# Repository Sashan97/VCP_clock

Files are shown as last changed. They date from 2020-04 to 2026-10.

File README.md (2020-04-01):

# VCP clock
Replica of Vilnius Central Post electronic clock

### CLOCK:
* 3D printed case
* Uses Arduino Nano, DS3231 RTC module and WS2812 LED strips
* Supports Bluetooth connection via HC06

### APP:
* Designed in Thunkable
* Allows to turn the clock on and off, adjust time and brightness and toggle lantern mode

### SERIAL PORT TERMINAL COMMUNICATION:

Some advanced clock settings can be changed through the serial port terminal via Bluetooth.

Command syntax:

set,arg1,arg2,arg3,arg4,arg5,arg6,arg7

* arg1 - power, 0 is off, 1 is on.
* arg2 - brightness, 0-255.
* arg3 - lantern mode, 0 is off, 1 is on.
* arg4 - color, 1 - original, 2 - red, 3 - green, 4 - blue.
* arg5 - auto mode, turns clock off and on at certain hours, 0 is off, 1 is on.
* arg6 - auto mode start hour, ignored if arg5 is 0.
* arg7 - auto mode stop our, ignored if arg5 is 0.

For example, sending **set,1,50,0,1,1,7,23** will turn the clock with the brightness 50, without the lantern mode, using original color. Automatic mode will shut down the clock at 23 and turn it on at 7 next day. Notice, that if the command will be sent between 23 and 7, time will not be shown.

Also you can override date and time via terminal by sending

time,arg1,arg2,arg3,arg4,arg5,arg6,arg7

* arg1 - hours 0-23
* arg2 - minutes
* arg3 - seconds
* arg4 - month 1-12
* arg5 - day
* arg6 - year (2 last digits)
* arg7 - day of week 1-7

For example, sending **time,14,21,0,3,4,20,2** will set the time and date to 14:21:00, 3rd of April, 2020, Tuesday.

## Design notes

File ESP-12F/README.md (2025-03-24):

### Idea
**Swap Arduino Nano to ESP-12F to enable time syncronization with time server.**

### Pros
- RTC clock module is redundant and can be removed - ESP-12F has RTC memery.
- Bluetooth module is redundant and can be removed - web page will be used to adjust settings.

### Cons
- ESP-12F is 3.3V, so the voltage regulator is necessary.
- Also logic level converter will be necessary to work with WS2812B RGB strips.

### Possible solutions
- Voltage regulator - AMS1117 or MP2315
- Logic level converter - 74HCT125
- WiFiManager.h library to manage Wi-Fi credentials

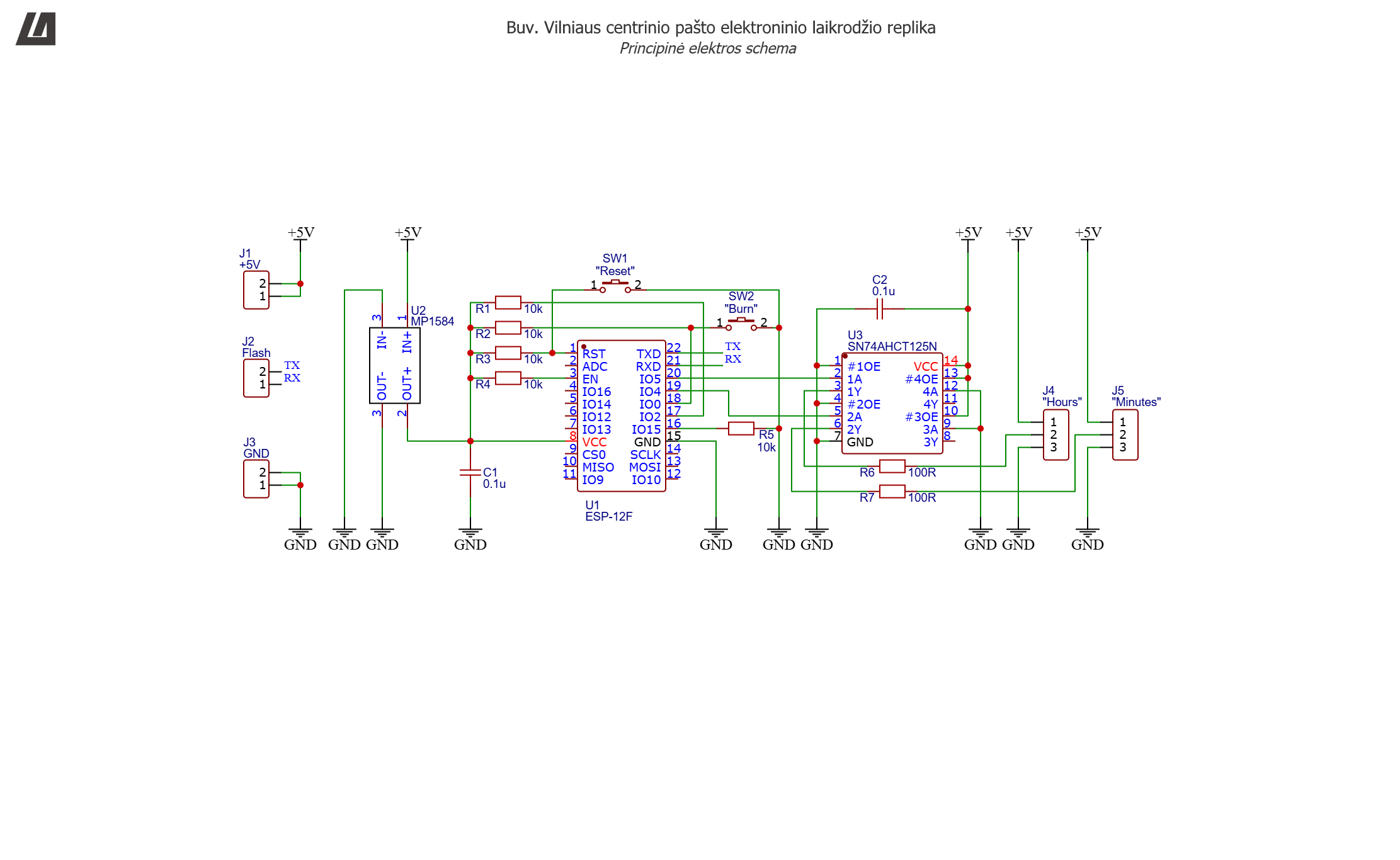
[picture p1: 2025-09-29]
ESP-12F/Hardware/circuit_diagram.png

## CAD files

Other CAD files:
3D/Clock_main v1.f3d

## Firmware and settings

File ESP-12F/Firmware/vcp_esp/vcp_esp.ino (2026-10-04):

#include <WiFiManager.h>
#include <ESP8266Wifi.h>
#include <ESP8266WebServer.h>
#include <WiFiUdp.h>
#include <Ticker.h>
#include <NTPClient.h>
#include <Adafruit_NeoPixel.h>
#include <EEPROM.h>

#define HOUR_LED_AMOUNT 36
#define MINUTE_LED_AMOUNT 72
#define HOURS_PIN 5
#define MINUTES_PIN 4

#define DEFAULT_OFFSET 2
#define DEFAULT_ON_HOUR 7
#define DEFAULT_ON_MINUTE 0
#define DEFAULT_OFF_HOUR 23
#define DEFAULT_OFF_MINUTE 0
#define DEFAULT_MAX_CONNECTION_ATTEMPTS 3
#define DEFAULT_WAIT_PER_ATTEMPT 30

ESP8266WebServer server(80);

WiFiUDP ntpUDP;
NTPClient timeClient(ntpUDP, "pool.ntp.org", 0, 3600000);

Ticker displayTicker;

WiFiManager wifiManager;

Adafruit_NeoPixel hourStrip = Adafruit_NeoPixel(HOUR_LED_AMOUNT, HOURS_PIN, NEO_GRB + NEO_KHZ800);
Adafruit_NeoPixel minuteStrip = Adafruit_NeoPixel(MINUTE_LED_AMOUNT, MINUTES_PIN, NEO_GRB + NEO_KHZ800);

int brightness = 50;
uint32_t color = 0;

bool clockActive = true;

struct ClockSettings {
  uint32_t magic;

  long utcOffsetInSeconds;
  bool autoOnOffEnabled;
  bool dstEnabled;
  int offHour;
  int offMinute;
  int onHour;
  int onMinute;
  int maxConnectionAttempts;
  int waitPerAttempt;
};

const uint32_t SETTINGS_MAGIC = 0x434C4B31; // "CLK1"

ClockSettings settings;

volatile bool displayUpdateRequested = false;

bool clockServerStarted = false;

bool portalAnimationPixels[MINUTE_LED_AMOUNT] = { false };
uint8_t portalAnimationPixelCount = 0;

unsigned long lastPortalAnimationUpdate = 0;

const unsigned long PORTAL_ANIMATION_INTERVAL = 3000UL;
const uint8_t PORTAL_ANIMATION_MAX_PIXELS = 10;

void requestDisplayUpdate() {
  displayUpdateRequested = true;
}

bool isInOnOffInterval(int curMin, int offMin, int onMin) {
  if (offMin == onMin) return false;
  if (offMin < onMin) {
    return (curMin >= offMin && curMin < onMin);
  } else {
    // for cases involving the transition through midnight
    return (curMin >= offMin) || (curMin < onMin);
  }
}

void saveSettings() {
  EEPROM.put(0, settings);
  EEPROM.commit();
}

void loadSettings() {
  EEPROM.get(0, settings);

  if (settings.magic != SETTINGS_MAGIC) {
    settings.utcOffsetInSeconds = DEFAULT_OFFSET * 3600;
    settings.autoOnOffEnabled = false;
    settings.dstEnabled = true;
    settings.offHour = DEFAULT_OFF_HOUR;
    settings.offMinute = DEFAULT_OFF_MINUTE;
    settings.onHour = DEFAULT_ON_HOUR;
    settings.onMinute = DEFAULT_ON_MINUTE;
    settings.maxConnectionAttempts = DEFAULT_MAX_CONNECTION_ATTEMPTS;
    settings.waitPerAttempt = DEFAULT_WAIT_PER_ATTEMPT;
    saveSettings();
  }
}

bool isDST(int year, int month, int day, int hourUTC) {
  int lastSundayMarch = 31 - ((5 * year / 4 + 4) % 7);
  int lastSundayOctober = 31 - ((5 * year / 4 + 1) % 7);

  if (month > 3 && month < 10) {
    return true;
  }

  if (month == 3) {
    if (day > lastSundayMarch) return true;
    if (day < lastSundayMarch) return false;

    return hourUTC >= 1;
  }

  if (month == 10) {
    if (day < lastSundayOctober) return true;
    if (day > lastSundayOctober) return false;

    return hourUTC < 1;
  }

  return false;
}

void updateTimeOffset() {
  timeClient.setTimeOffset(0);

  time_t utcTime = timeClient.getEpochTime();
  struct tm *utcInfo = gmtime(&utcTime);

  bool dst = false;

  if (settings.dstEnabled) {
    dst = isDST(
      utcInfo->tm_year + 1900,
      utcInfo->tm_mon + 1,
      utcInfo->tm_mday,
      utcInfo->tm_hour
    );
  }

  long effectiveOffset = settings.utcOffsetInSeconds;

  if (dst) {
    effectiveOffset += 3600L;
  }

  timeClient.setTimeOffset(effectiveOffset);
}

void setHourPixels(int hours) {
  hourStrip.clear();
  int hourLedIndex = hours * 3;

  if (hours >= 12)
    hourLedIndex -= 36;

  for (int i = hourLedIndex; i < (hourLedIndex + 3); i++) {
    hourStrip.setPixelColor(i, color);
  }
}

void setMinutePixels(int minutes) {
  if (minutes == 0) {
    minuteStrip.clear();
  }

  int minutesUntilTile = 5;
  int tileAmount = minutes + minutes / 5;

  for (int i = 0; i < tileAmount; i++) {
    if (minutesUntilTile > 0) {
      minuteStrip.setPixelColor(i, color);
      minutesUntilTile--;
    } else {
      minuteStrip.setPixelColor(i, 0x000000);
      minutesUntilTile = 5;
    }
  }
}

void displayTime() {
  Serial.println(timeClient.getFormattedTime());

  int hours = timeClient.getHours();
  int minutes = timeClient.getMinutes();

  int minutesSinceMidnight = hours * 60 + minutes;
  int offMin = settings.offHour * 60 + settings.offMinute;
  int onMin = settings.onHour * 60 + settings.onMinute;

  bool shouldBeActive = true;
  if (settings.autoOnOffEnabled) {
    if (isInOnOffInterval(minutesSinceMidnight, offMin, onMin)) {
      shouldBeActive = false;
    } else {
      shouldBeActive = true;
    }
  }

  if (shouldBeActive != clockActive) {
    clockActive = shouldBeActive;
    if (!clockActive) {
      hourStrip.clear();
      minuteStrip.clear();
      hourStrip.show();
      minuteStrip.show();
    } else {
      setHourPixels(hours);
      hourStrip.show();
      setMinutePixels(minutes);
      minuteStrip.show();
    }
  }

  if (!clockActive) return;

  // Display hours
  setHourPixels(hours);
  hourStrip.show();

  // Display minutes
  setMinutePixels(minutes);
  minuteStrip.show();
}

bool isMinuteSeparatorPixel(int pixel) {
  // Minute strip is arranged as:
  // 5 minute LEDs, 1 separator, repeated.
  return (pixel % 6) == 5;
}


void resetConfigPortalAnimation() {
  for (int i = 0; i < MINUTE_LED_AMOUNT; i++) {
    portalAnimationPixels[i] = false;
  }

  portalAnimationPixelCount = 0;

  // Make the first pixel appear immediately.
  lastPortalAnimationUpdate = millis() - PORTAL_ANIMATION_INTERVAL;

  // Remove the old clock display when entering ConfigPortal.
  hourStrip.clear();
  minuteStrip.clear();

  hourStrip.show();
  minuteStrip.show();
}

void updateConfigPortalAnimation() {
  unsigned long now = millis();

  if (now - lastPortalAnimationUpdate < PORTAL_ANIMATION_INTERVAL) {
    return;
  }

  lastPortalAnimationUpdate = now;

  // Pick a new, currently inactive, non-separator pixel.
  int newPixel;

  do {
    newPixel = random(MINUTE_LED_AMOUNT);
  }
  while (
    isMinuteSeparatorPixel(newPixel) ||
    portalAnimationPixels[newPixel]
  );

  portalAnimationPixels[newPixel] = true;
  portalAnimationPixelCount++;

  if (portalAnimationPixelCount > PORTAL_ANIMATION_MAX_PIXELS) {
    int pixelToRemove;

    do {
      pixelToRemove = random(MINUTE_LED_AMOUNT);
    }
    while (
      isMinuteSeparatorPixel(pixelToRemove) ||
      !portalAnimationPixels[pixelToRemove] ||
      pixelToRemove == newPixel
    );

    portalAnimationPixels[pixelToRemove] = false;
    portalAnimationPixelCount--;
  }

  // Render complete animation state.
  minuteStrip.clear();

  for (int i = 0; i < MINUTE_LED_AMOUNT; i++) {
    if (portalAnimationPixels[i]) {
      minuteStrip.setPixelColor(i, color);
    }
  }

  minuteStrip.show();
}

void handleRoot() {
  int tzHours = settings.utcOffsetInSeconds / 3600;

  uint32_t c = color;
  uint8_t r = (c >> 16) & 0xFF;
  uint8_t g = (c >> 8) & 0xFF;
  uint8_t b = c & 0xFF;
  char colorHex[8];
  sprintf(colorHex, "#%02X%02X%02X", r, g, b);

  char offBuf[6], onBuf[6];
  sprintf(offBuf, "%02d:%02d", settings.offHour, settings.offMinute);
  sprintf(onBuf, "%02d:%02d", settings.onHour, settings.onMinute);

  String autoOnOffChecked = settings.autoOnOffEnabled ? "checked" : "";
  String dstChecked = settings.dstEnabled ? "checked" : "";

  String page = String(R"rawliteral(
  <!DOCTYPE html>
  <html>
  <head>
    <meta charset="UTF-8">
    <title>Clock Settings</title>
    <style>
      body { font-family: Arial, sans-serif; margin: 20px; background: #f5f5f5; }
      h1 { color: #222; }
      form { background: #fff; padding: 20px; border-radius: 8px; box-shadow: 0 0 5px rgba(0,0,0,0.2); max-width: 420px; }
      label { display: block; margin-top: 12px; }
      input[type=number], input[type=color], input[type=time] {
        padding: 6px; width: 100%; box-sizing: border-box; margin-top: 6px;
      }
      input[type=submit] {
        margin-top: 18px; padding: 10px 18px;
        background: #4CAF50; color: white; border: none;
        border-radius: 4px; cursor: pointer;
      }
      input[type=submit]:hover { background: #45a049; }
    </style>
  </head>
  <body>
    <h1>Clock Settings</h1>
    <form action="/save" method="POST">
  )rawliteral");

  page += String("<label>Timezone offset (hours):<input type=\"number\" name=\"tz\" value=\"") + String(tzHours) + String("\" step=\"1\" min=\"-12\" max=\"12\"></label>\n");

  page += "<label><input type=\"checkbox\" name=\"auto_dst\" " + dstChecked + "> Perform DST trasition</label>\n";

  page += String("<label>Brightness (0-255):<input type=\"number\" name=\"brightness\" value=\"") + String(brightness) + String("\" min=\"0\" max=\"255\"></label>\n");

  page += String("<label>LED color:<input type=\"color\" name=\"color\" value=\"") + String(colorHex) + String("\"></label>\n");

  page += "<label><input type=\"checkbox\" name=\"auto_onoff\" " + autoOnOffChecked + "> Enable automatic on/off</label>\n";

  page += String("<label>Auto-off start time:<input type=\"time\" name=\"off_time\" value=\"") + String(offBuf) + String("\"></label>\n");

  page += String("<label>Auto-on start time:<input type=\"time\" name=\"on_time\" value=\"") + String(onBuf) + String("\"></label>\n");

  page += String("<label>Wi-Fi connection attempts (0-10):<input type=\"number\" name=\"max_attempts\" value=\"") + String(settings.maxConnectionAttempts) + String("\" min=\"0\" max=\"10\"></label>\n");

  page += String("<label>Wait per attempt, s (0-100):<input type=\"number\" name=\"wait_per_attempt\" value=\"") + String(settings.waitPerAttempt) + String("\" min=\"0\" max=\"100\"></label>\n");
  
  page += R"rawliteral(
      <input type="submit" value="Save settings">
    </form>
  </body>
  </html>
  )rawliteral";

  page += R"rawliteral(
  <hr>
  <form action="/forget" method="POST">
    <input type="submit" value="Forget Wi-Fi and reboot">
  </form>
  )rawliteral";

  server.send(200, "text/html", page);
}

void handleSave() {
  if (server.hasArg("tz")) {
    int tz = server.arg("tz").toInt();
    settings.utcOffsetInSeconds = tz * 3600;
  }

  if (server.hasArg("auto_dst")) {
    settings.dstEnabled = true;
  } else {
    settings.dstEnabled = false;
  }

  if (server.hasArg("brightness")) {
    int b = server.arg("brightness").toInt();
    if (b < 0) b = 0;
    if (b > 255) b = 255;
    brightness = b;

    hourStrip.setBrightness(brightness);
    minuteStrip.setBrightness(brightness);
  }

  if (server.hasArg("color")) {
    String hex = server.arg("color");  // например, "#fca503"
    long number = strtol(hex.substring(1).c_str(), NULL, 16);

    int r = (number >> 16) & 0xFF;
    int g = (number >> 8) & 0xFF;
    int b = number & 0xFF;

    color = minuteStrip.Color(r, g, b);
  }

  if (server.hasArg("auto_onoff")) {
    settings.autoOnOffEnabled = true;
  } else {
    settings.autoOnOffEnabled = false;
  }

  if (server.hasArg("off_time")) {
    String offTime = server.arg("off_time");
    if (offTime.length() >= 5) {
      settings.offHour = offTime.substring(0, 2).toInt();
      settings.offMinute = offTime.substring(3, 2 + 3).toInt();
    }
  }

  if (server.hasArg("on_time")) {
    String onTime = server.arg("on_time");
    if (onTime.length() >= 5) {
      settings.onHour = onTime.substring(0, 2).toInt();
      settings.onMinute = onTime.substring(3, 2 + 3).toInt();
    }
  }

  if (server.hasArg("max_attempts")) {
    int attempts = server.arg("max_attempts").toInt();
    if (attempts < 0) attempts = 0;
    if (attempts > 10) attempts = 10;
    settings.maxConnectionAttempts = attempts;
  }

  if (server.hasArg("wait_per_attempt")) {
    int delay = server.arg("wait_per_attempt").toInt();
    if (delay < 0) delay = 0;
    if (delay > 100) delay = 100;
    settings.waitPerAttempt = delay;
  }

  saveSettings();

  updateTimeOffset();

  server.send(200, "text/html",
              "<h1>Settings saved!</h1><p><a href='/'>Back to settings</a></p>");
}

void handleNotFound() {
  server.send(404, "text/plain", "Not found");
}

void startClockConfigPortal() {
  Serial.println("Starting ConfigPortal...");

  resetConfigPortalAnimation();

  wifiManager.startConfigPortal("VCP-Clock");
}

void startClockServer() {
  if (clockServerStarted) {
    return;
  }

  server.begin();
  clockServerStarted = true;

  Serial.println("Clock web server started.");
}

void connectWiFiOrPortal() {
  if (!wifiManager.getWiFiIsSaved()) {
  Serial.println("No saved Wi-Fi credentials.");
  startClockConfigPortal();
  return;
}
  
  WiFi.begin();

  bool connected = false;

  int pos = 0;
  int dir = 1;
  unsigned long lastAnim = 0;
  const unsigned long animInterval = 500;

  for (int attempt = 1; attempt <= settings.maxConnectionAttempts; attempt++) {
    unsigned long start = millis();
    while (WiFi.status() != WL_CONNECTED && (millis() - start) < (settings.waitPerAttempt * 1000)) {
      delay(50);

      if (millis() - lastAnim > animInterval) {
        lastAnim = millis();

        minuteStrip.clear();
        if (pos < 5) {
          minuteStrip.setPixelColor(pos, minuteStrip.Color(255, 0, 0));
        }
        minuteStrip.show();

        pos += dir;
        if (pos == 0 || pos == 4) dir = -dir;
      }
    }
    if (WiFi.status() == WL_CONNECTED) {
      connected = true;
      break;
    }
  }

  minuteStrip.clear();
  minuteStrip.show();

  if (!connected) {
    startClockConfigPortal();
  }
}

void handleForgetWiFi() {
  server.send(200, "text/html",
              "<h1>Forgetting Wi-Fi...</h1><p>Device will reboot.</p>");
  
  delay(200);

  wifiManager.resetSettings();

  delay(500);
  ESP.restart();
}

void setup() {
  pinMode(HOURS_PIN, OUTPUT);
  pinMode(MINUTES_PIN, OUTPUT);

  Serial.begin(9600);
  EEPROM.begin(512);
  loadSettings();

  hourStrip.begin();
  minuteStrip.begin();

  hourStrip.setBrightness(brightness);
  minuteStrip.setBrightness(brightness);
  color = minuteStrip.Color(252, 165, 3);

  WiFi.mode(WIFI_STA);
  wifiManager.setConfigPortalBlocking(false);
  wifiManager.setDisableConfigPortal(true);

  randomSeed(micros());

  connectWiFiOrPortal();

  timeClient.begin();
  timeClient.setTimeOffset(0);

  if (timeClient.update()) {
    updateTimeOffset();
  }

  displayTicker.attach(1, requestDisplayUpdate);

  server.on("/", handleRoot);
  server.on("/save", HTTP_POST, handleSave);
  server.on("/forget", HTTP_POST, handleForgetWiFi);
  server.onNotFound(handleNotFound);
  if (!wifiManager.getConfigPortalActive()) {
    startClockServer();
  }
}

void loop() {
  // ------------------------------------------------------------
  // CONFIG PORTAL MODE
  // ------------------------------------------------------------
  if (wifiManager.getConfigPortalActive()) {

    bool connected = wifiManager.process();

    displayUpdateRequested = false;

    if (connected && WiFi.status() == WL_CONNECTED) {
      Serial.println("Wi-Fi configured successfully.");

      startClockServer();

      if (timeClient.forceUpdate()) {
        updateTimeOffset();
      }

      minuteStrip.clear();
      minuteStrip.show();

      displayTime();

      return;
    }

    updateConfigPortalAnimation();

    return;
  }


  // ------------------------------------------------------------
  // NORMAL CLOCK MODE
  // ------------------------------------------------------------
  if (!clockServerStarted && WiFi.status() == WL_CONNECTED) {
    startClockServer();
  }

  if (clockServerStarted) {
    server.handleClient();
  }


  if (displayUpdateRequested) {
    displayUpdateRequested = false;
    displayTime();
  }


  if (timeClient.update()) {
    updateTimeOffset();
  }


  static unsigned long lastDstCheck = 0;

  if (millis() - lastDstCheck >= 60000UL) {
    lastDstCheck = millis();
    updateTimeOffset();
  }
}

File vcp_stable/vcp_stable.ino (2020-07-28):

#include <Adafruit_NeoPixel.h>
#include <iarduino_RTC.h>

int lastMinute;
int lastMode;
bool isOn = true;
bool isActive = true;

//settings
int bpower = 1;       // 0 - off, 1 - on
int bbright = 50;      // brightness 0-250
int bmodes = 1;       // 1 - clock, 2 - illumination, 3 - lamp
int bcolor = 1;       // 1 - original, 2 - red, 3 - green, 4 - blue
int bauto = 0;        // automatic start and stop 0 - off, 1 - on
int bautostart = 0;   //start time, if auto is on
int bautostop = 0;    //stop time, if auto is off

//bluetooth data input
const byte numChars = 32;
char receivedChars[numChars];
char tempChars[numChars];        // temporary array for use when parsing
bool newData = false;

String mode;            // set time (time) or adjust settings (set)

int arg1 = 0;
int arg2 = 0;
int arg3 = 0;
int arg4 = 0;
int arg5 = 0;
int arg6 = 0;
int arg7 = 0;

//LED strips
Adafruit_NeoPixel hourStrip = Adafruit_NeoPixel(36, 13, NEO_GRB + NEO_KHZ800);
Adafruit_NeoPixel minuteStrip = Adafruit_NeoPixel(72, 12, NEO_GRB + NEO_KHZ800);

uint32_t orig = minuteStrip.Color(252,165,3);
uint32_t currentColor;

//Clock
iarduino_RTC time(RTC_DS3231);

void setup(){
  lastMinute=61;
  currentColor = orig;
  hourStrip.begin();
  minuteStrip.begin();
  minuteStrip.setBrightness(bbright);    // яркость, от 0 до 255
  hourStrip.setBrightness(bbright);
  minuteStrip.clear();                          // очистить
  minuteStrip.show();                           // отправить на ленту
  hourStrip.clear();
  hourStrip.show();
  Selftest();
  time.begin();
  time.settime(0,0,12,1,1,15,1);  // 0  сек, 51 мин, 21 час, 27, октября, 2015 года, вторник
  Serial.begin(9600);
}

void indicate(int hrStrip, int minStrip){
  //часы
  byte hourIndex;
  if(hrStrip < 12) hourIndex = hrStrip * 3;
  else hourIndex = hrStrip * 3 - 36; 
  hourStrip.clear();
  for(int i = hourIndex; i < (hourIndex + 3); i++){
    hourStrip.setPixelColor(i, currentColor);
  }
  hourStrip.show();
  lastMinute = minStrip;
  
  // минуты

  if(minStrip == 0){
    minuteStrip.clear();
    minuteStrip.show();
  }
  byte minToTile = 5;
  int tiles = minStrip + minStrip/5; //кол-во клеток периметра
  for(int i = 0; i < tiles; i++){
    if(minToTile > 0){
      minuteStrip.setPixelColor(i, currentColor);
      minToTile--;
    }
    else{
      minuteStrip.setPixelColor(i, 0x000000);
      minToTile = 5;
    }
  }
  minuteStrip.show();
}

void updateTime(){
  if(millis()%1000==0){ // если прошла 1 секунда
      time.gettime();
      //проверяем изменилось ли время
      indicate(time.Hours, time.minutes);
      //Serial.println(time.gettime("d-m-Y, H:i:s, D")); // выводим время
  }
}

void updateBluetooth(){
  static byte ndx = 0;
    char endMarker = '\n';
    char rc;
    
    while (Serial.available() > 0 && newData == false) {
        rc = Serial.read();

        if (rc != endMarker) {
            receivedChars[ndx] = rc;
            ndx++;
            if (ndx >= numChars) {
                ndx = numChars - 1;
            }
        }
        else {
            receivedChars[ndx] = '\0'; // terminate the string
            ndx = 0;
            newData = true;
        }
    }
}

void applySettings(){
  bpower = arg1;
  
  bbright = arg2;
  hourStrip.setBrightness(bbright);
  minuteStrip.setBrightness(bbright);

  bmodes = arg3;

  bcolor = arg4;
  switch(bcolor){
    case 1:
      currentColor = orig;
      break;

    case 2:
      Serial.println(currentColor);
      currentColor = minuteStrip.Color(256,1,1);
      Serial.println(currentColor);
      break;

    case 3:
      currentColor = orig;
      break;
      
    case 4:
      currentColor = minuteStrip.Color(0,0,256);
      break;
  }

  bauto = arg5;
  bautostart = arg6;
  bautostop = arg7;
}

void checkNewData(){
  if (newData == true) {
        strcpy(tempChars, receivedChars);
            // this temporary copy is necessary to protect the original data
            //   because strtok() used in parseData() replaces the commas with \0
        parseData();
        if(mode == "set") applySettings();
        else{
          minuteStrip.clear();
          minuteStrip.show();
          time.settime(arg3, arg2, arg1, arg5, arg4, arg6, arg7);
        }
        newData = false;
  }
}

void parseData(){
  char * strtokIndx; // this is used by strtok() as an index
  
    strtokIndx = strtok(tempChars, ",");
    mode = strtokIndx;
    strtokIndx = strtok(NULL, ",");
    arg1 = atoi(strtokIndx);
    strtokIndx = strtok(NULL, ",");
    arg2 = atoi(strtokIndx);
    strtokIndx = strtok(NULL, ",");
    arg3 = atoi(strtokIndx);
    strtokIndx = strtok(NULL, ",");
    arg4 = atoi(strtokIndx);
    strtokIndx = strtok(NULL, ",");
    arg5 = atoi(strtokIndx);
    strtokIndx = strtok(NULL, ",");
    arg6 = atoi(strtokIndx);
    strtokIndx = strtok(NULL, ",");
    arg7 = atoi(strtokIndx);
}

void loop(){
  updateBluetooth();
  checkNewData();

  if(bpower == 1){
    isOn = true;
    
    if(bmodes == 1){ 
      if(lastMode == 2){     //if mode1 selected after mode2
        minuteStrip.clear();
        minuteStrip.show();
        lastMode = 1;
      }
      if(bauto == 0) {
        updateTime();
      }
      else if(bauto == 1){
        autoTime();
      }
    }
    else if(bmodes == 2){ // lantern mode
      hourStrip.fill(currentColor);
      hourStrip.show();
      minuteStrip.fill(currentColor);
      minuteStrip.show();
      lastMode = 2;
    }
  }
  else{ //if turned off
    turnoff();
  }
}

void autoTime(){
  if(millis()%1000==0){
    time.gettime();
  }
  if (time.Hours>=bautostart && time.Hours<bautostop){
      updateTime();
  }
  else{
    hourStrip.clear();
    hourStrip.show();
    minuteStrip.clear();
    minuteStrip.show();
  }
}

void turnoff(){
  if(isOn){
    hourStrip.clear();
    hourStrip.show();
    minuteStrip.clear();
    minuteStrip.show();
    isOn = false;
  }
}
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

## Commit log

2020-04-01 Added main files
    Added 3d model file (Autodesk Fusion 360), Arduino firmware (.ino), Thunkable Android app project file (.aia) and app installer (.apk)
    [Clock_main v1.f3d]
2020-07-28 Fixed auto time mode
    Made time.gettime to execute eventually even when time indication is off
    [vcp_stable.ino]
2025-03-31 Added circuit diagram for ESP version
2025-09-29 Add headers, change 5v to 3.3v converter circuit
2025-09-30 Change minutes pin assignement, configure outputs
2025-10-07 Implement network change button
2025-11-23 Fix wait_per_attempt value range
    [vcp_esp.ino]
2026-10-04 Fixed DST apply bug
    [vcp_esp.ino]
